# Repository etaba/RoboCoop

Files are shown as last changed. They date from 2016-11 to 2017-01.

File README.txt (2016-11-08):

To set the alarms:
	1) Basic operation: Click NEXT to cycle through the different RoboCoop settings. Click SEL to interact with a setting.
	2) To set the alarms: Cycle through the 4 alarm-setting screens and change the 	hours and minutes of the alarms by using SEL to increase the value.
	3) To set the time: Press NEXT until the screen says SETTING TIME. Press SEL to select the hour. Press NEXT and then repeat to select the minute.
	4) To toggle the alarm on and off, press SEL while on the first screen which displays the time and the state of the alarm.
	5) To disconnect the motor from the pulley, pull apart the pulley bolt from the magnetic bit socket of the motor. The motor pivots downward to make this possible. The pulley is then free and the door can be adjusted. Note that the solenoid door lock will need to be pushed in to allow the door to close
	6) If the screen reads "ERROR", it has fallen in a bad state and must be manually readjusted. Unplug RoboCoop and follow the instructions to manually readjust the door. When the door is closed and locked, restart RoboCoop.

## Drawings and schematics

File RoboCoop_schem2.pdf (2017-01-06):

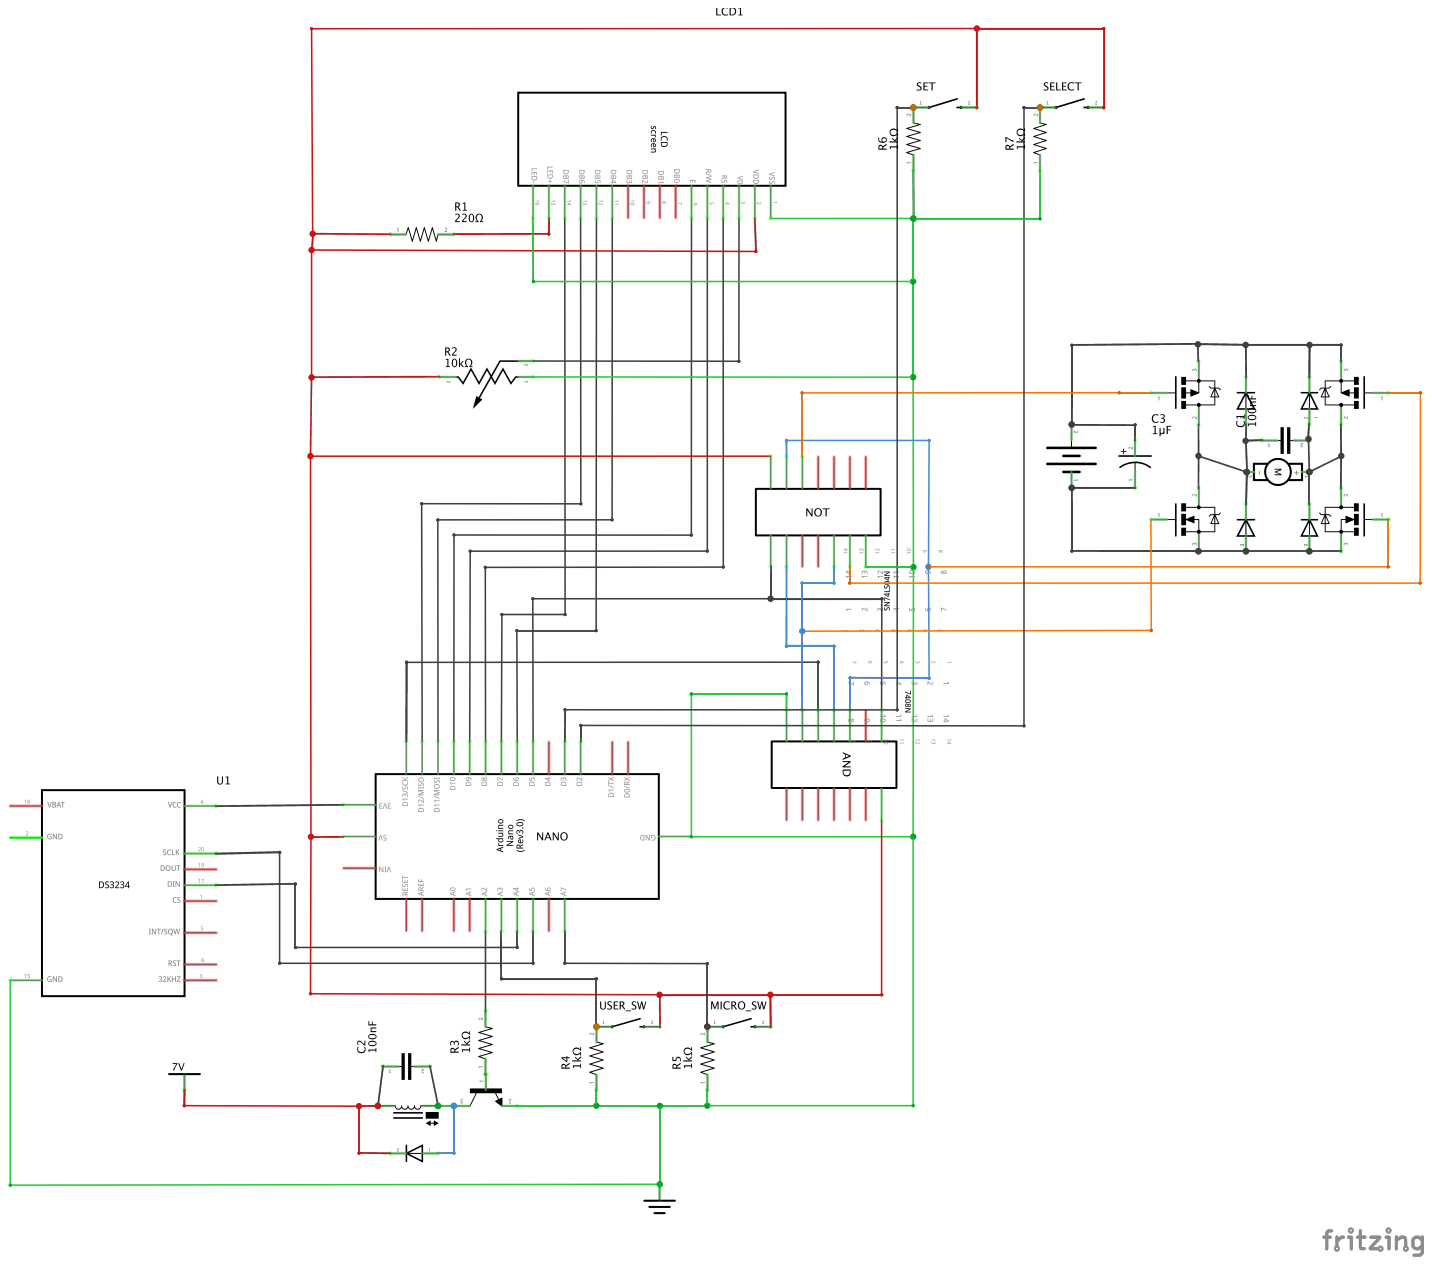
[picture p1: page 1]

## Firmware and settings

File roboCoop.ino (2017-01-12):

//v2.0

#include <Time.h>
#include <TimeLib.h>
#include "roboCoop.h"
#include <LiquidCrystal.h>
#include "Wire.h"
#define DS3231_I2C_ADDRESS 0x68


//inputs (switches)
int switch_p = A3; //D2
int doorStop_p = A7; //D3
int setButton_p = 2;
int selectButton_p = 3;

//outputs (to actuators)
int solenoidEn_p = A2;
int motorDirection_p = 5; //0 -> counter-clockwise, 1 -> clockwise
int motorEn_p = 4;

//LCD pins
int d4_p = 11;
int d5_p = 6;
int d6_p = 12;
int d7_p = 7;
int rs_p = 8;
int en_p = 10;
int rw_p = 9;

LiquidCrystal lcd(rs_p, en_p, d4_p, d5_p, d6_p, d7_p); 
String currScreen;

//state variables
int doorState; //0 -> closed, 1 -> open
int switchState; //0 -> switch off, 1 -> switch on
bool alarmState; //True -> alarm on
bool flipFlag; //To determine if the switch logic need to be reversed
int prevSwitchState; //To detect switch has been flipped
int currSwitchState;

TimeElements openAlarm;
TimeElements closeAlarm;
time_t timeOut;

machine_state_t machineState;
set_time_state_t setState;


void setup()
{
  Wire.begin();
  Serial.begin(9600);

  pinMode(13,OUTPUT);
  
  pinMode(motorDirection_p,OUTPUT);
  pinMode(motorEn_p, OUTPUT);
  pinMode(solenoidEn_p,OUTPUT);
  pinMode(rw_p,OUTPUT);
  
  pinMode(switch_p, INPUT);
  pinMode(setButton_p,INPUT);
  pinMode(selectButton_p,INPUT);
  pinMode(doorStop_p,INPUT);

  digitalWrite(motorEn_p, LOW);
  digitalWrite(motorDirection_p,LOW);
  digitalWrite(solenoidEn_p,LOW);
  digitalWrite(rw_p,LOW);
  
  //DEFAULT time and alarms   
  setCurrTime(12,0);
  openAlarm.Hour = 6;
  openAlarm.Minute = 30;
  closeAlarm.Hour = 20;
  closeAlarm.Minute = 0;

  alarmState = true;
  flipFlag = digitalRead(switch_p) == digitalRead2(doorStop_p);
  prevSwitchState = digitalRead(switch_p);
  machineState = READY;
}

void mockDoor(bool openDoor)
{
  if (openDoor)
  for(int i = 0; i < 5; i++)
  {
     digitalWrite(13,i%2);
     delay(500);
  }
  else
  for(int i = 0; i < 50; i++)
  {
     digitalWrite(13,i%2);
     delay(100);
  }
}

void loop()
{
  //for testing:
  if(false){
    while(digitalRead2(doorStop_p))
    {
      digitalWrite(13,HIGH);
      digitalWrite(solenoidEn_p,HIGH);
    }
    digitalWrite(13,LOW);
      digitalWrite(solenoidEn_p,LOW);
  }
  else{
  switch(machineState)
  {
    case READY:
      doorState = !digitalRead2(doorStop_p); //LOW->closed, HIGH->open
      currSwitchState = digitalRead(switch_p);
      switchState =  currSwitchState ^ flipFlag; //HIGH->on, LOW->off
      lcdShowTime("Time: ", getCurrTime(), (alarmState ? "Alarm On" : "Alarm Off"));
      if (currSwitchState != prevSwitchState &&
          switchState != doorState) //door must be opened or closed
      {
        machineState = (switchState==HIGH) ? OPENING : CLOSING;
      }
      prevSwitchState = currSwitchState;
      if(alarmState && doorState==LOW && checkAlarm(openAlarm))
      {
        machineState = OPENING;
        flipFlag = !flipFlag;
      }
      else if (alarmState && doorState==HIGH && checkAlarm(closeAlarm))
      {
        machineState = CLOSING;
        flipFlag = !flipFlag;
      }
      if (digitalRead(setButton_p) == HIGH)
      {
         machineState = SET;
         setState = OPEN_HOUR;
         timeOut = now();
         delay(500);
      }
      if (digitalRead(selectButton_p) == HIGH) //toggle alarm
      {
        alarmState = !alarmState;
      }
      break;

    case SET:
      if (now() - timeOut > 60)
      {
        machineState = READY;
      }
      switch(setState)
      {
        case OPEN_HOUR:
          lcdShowTime("Open at: ",openAlarm, "SETTING HOUR");
          if (digitalRead(selectButton_p)==HIGH)
          {
            if (openAlarm.Hour == 23)
              openAlarm.Hour = 0;
            else
              openAlarm.Hour += 1;
            delay(250);
          }
          if (digitalRead(setButton_p))
          {
            setState = OPEN_MINUTE;
            timeOut = now();
            delay(500);
          }
          break;
          
        case OPEN_MINUTE: 
          lcdShowTime("Open at: ",openAlarm,"SETTING MINUTE");
          if (digitalRead(selectButton_p)==HIGH)
          {
            if (openAlarm.Minute == 59)
              openAlarm.Minute = 0;
            else
              openAlarm.Minute += 1;
            delay(250);
          }
          if (digitalRead(setButton_p))
          {
            setState = CLOSE_HOUR;
            timeOut = now();
            delay(500); 
          }
          break;
          
        case CLOSE_HOUR:
          lcdShowTime("Close at: ",closeAlarm,"SETTING HOUR");
          if (digitalRead(selectButton_p)==HIGH)
          {
            if (closeAlarm.Hour == 23)
              closeAlarm.Hour = 0;
            else
              closeAlarm.Hour += 1;
            delay(250);
          }
          if (digitalRead(setButton_p))
          {
            setState = CLOSE_MINUTE;
            timeOut = now();
            delay(500); 
          }
          break;
          
        case CLOSE_MINUTE: 
          lcdShowTime("Close at: ",closeAlarm,"SETTING MINUTE");
          if (digitalRead(selectButton_p)==HIGH)
          {
            if (closeAlarm.Minute == 59)
              closeAlarm.Minute = 0;
            else
              closeAlarm.Minute += 1;
            delay(250);
          }
          if (digitalRead(setButton_p))
          {
            setState = TIME_HOUR;
            timeOut = now();
            delay(500); 
          }
          break;

        case TIME_HOUR:
          {
            TimeElements currTime = getCurrTime();
            lcdShowTime("Time: ",currTime,"SETTING HOUR");
            if (digitalRead(selectButton_p)==HIGH)
            {
              if (currTime.Hour == 23)
                currTime.Hour = 0;
              else
                currTime.Hour += 1;
              setCurrTime(currTime.Hour, currTime.Minute);
              delay(250);
            }
            if (digitalRead(setButton_p))
            {
              setState = TIME_MINUTE;
              timeOut = now();
              delay(500); 
            }
          }
          break;

        case TIME_MINUTE:
        {
          TimeElements t = getCurrTime();
          lcdShowTime("Time: ",t,"SETTING MINUTE");
          if (digitalRead(selectButton_p)==HIGH)
          {
            if (t.Minute == 59)
              t.Minute = 0;
            else
              t.Minute += 1;
            setCurrTime(t.Hour, t.Minute);
            delay(250);
          }
          if (digitalRead(setButton_p))
          {
            currSwitchState = digitalRead(switch_p);
            machineState = READY;
            delay(500); 
          }
        }
        break;
      }
      break;
    case OPENING: //activate door
      if (!operateDoor(HIGH))
      {
        machineState = ERROR_STATE;
      }
      else
      {
        machineState = READY;
      }
      break;
    case CLOSING:
      if (!operateDoor(LOW))
      {
        machineState = ERROR_STATE;
      }
      else
      {
        machineState = READY;
      }
      break;
    case MANUAL: //manual operation of door
      while(currSwitchState != digitalRead(switch_p))
      {
        digitalWrite(motorDirection_p,HIGH);
        digitalWrite(motorEn_p,HIGH);
        digitalWrite(solenoidEn_p,HIGH);
      }
      digitalWrite(solenoidEn_p,LOW);
      digitalWrite(motorEn_p,LOW);
      while(digitalRead(selectButton_p))
      {
        digitalWrite(motorDirection_p,LOW);
        digitalWrite(motorEn_p,HIGH);
        digitalWrite(solenoidEn_p,HIGH);
      }
      digitalWrite(solenoidEn_p,LOW);
      digitalWrite(motorEn_p,LOW);
      if (digitalRead(setButton_p))
      {
        flipFlag = digitalRead(switch_p) == digitalRead2(doorStop_p);
        machineState = READY;
        delay(500); 
      }
      break;
    case ERROR_STATE: //error, to prompt user to reset system
      lcdPrint("     ERROR!","RESET MANUALLY");
      delay (10000);
      break;
  }
  }
}

void lcdPrint(String header, String sub)
{
  lcd.clear();
  lcd.begin(16, 2);
  lcd.print(header);
  lcd.setCursor(1,2);
  lcd.print(sub);
}

void lcdShowTime(String prefix, TimeElements t, String details)
{
  
  String formattedTime = formatTime(t.Hour,t.Minute); 
  // Print a message to the LCD.
  if (currScreen != formattedTime + details)
  {
    lcd.clear();
    lcd.begin(16, 2);
    lcd.print(prefix + formattedTime);
    currScreen = formattedTime + details;
    if (details != "")
    {
      lcd.setCursor(1,2);
      lcd.print(details);
    }
  }
}

String formatTime(int t_hour, int t_minute)
{
  String dispHour;
  String dispMinute;
  dispHour = t_hour < 10 ? "0" + String(t_hour) : String(t_hour);
  dispMinute = t_minute < 10 ? "0" + String(t_minute) : String(t_minute);
  return dispHour + ":" + dispMinute;
}

bool operateDoor(bool openDoor) 
{
  //mockDoor(openDoor);
  //return;
  //digitalWrite(13,HIGH);
  time_t start = now();
  digitalWrite(motorDirection_p, !openDoor);
  if (openDoor && digitalRead2(doorStop_p)) //opening door
  {
    digitalWrite(solenoidEn_p, HIGH);
    delay(250); //TODO: calibrate
    digitalWrite(motorEn_p,HIGH);
    delay(1000);
    if (digitalRead2(doorStop_p)) //error if microswitch still closed after opening door for 500ms
    {
      digitalWrite(motorEn_p, LOW);
      digitalWrite(solenoidEn_p,LOW);
      return false;
    }
    delay (1750 );
    digitalWrite(motorEn_p,LOW);
    digitalWrite(solenoidEn_p, LOW);
  }
  else //closing door
  {
    digitalWrite(motorEn_p, HIGH);
    digitalWrite(solenoidEn_p,HIGH);
    while (!digitalRead2(doorStop_p))
    {
        if (now() - start > 3) //something is blocking the door or messing with the microswitch
        {
          digitalWrite(motorEn_p, LOW);
          digitalWrite(solenoidEn_p,LOW);
          return false;
        }
        delay(1);
    }
    digitalWrite(motorEn_p, LOW);
    digitalWrite(solenoidEn_p,LOW);
  }
  digitalWrite(13,LOW);
  delay(1000);
  return true;
}

bool checkAlarm(TimeElements alarm)
{
  byte t_second, t_minute, t_hour, dayOfWeek, dayOfMonth, t_month, t_year;
  readDS3231time(&t_second, &t_minute, &t_hour, &dayOfWeek, &dayOfMonth, &t_month, &t_year);
  return (alarm.Hour == int(t_hour) && alarm.Minute == int(t_minute) && int(t_second) == 0) ? true : false; 
}

// Convert normal decimal numbers to binary coded decimal
byte decToBcd(byte val)
{
  return( (val/10*16) + (val%10) );
}
// Convert binary coded decimal to normal decimal numbers
byte bcdToDec(byte val)
{
  return( (val/16*10) + (val%16) );
}

void setDS3231time(byte t_second, byte t_minute, byte t_hour, byte dayOfWeek, byte
dayOfMonth, byte t_month, byte t_year)
{
  // sets time and date data to DS3231
  Wire.beginTransmission(DS3231_I2C_ADDRESS);
  Wire.write(0); // set next input to start at the seconds register
  Wire.write(decToBcd(t_second)); // set seconds
  Wire.write(decToBcd(t_minute)); // set minutes
  Wire.write(decToBcd(t_hour)); // set hours
  Wire.write(decToBcd(dayOfWeek)); // set day of week (1=Sunday, 7=Saturday)
  Wire.write(decToBcd(dayOfMonth)); // set date (1 to 31)
  Wire.write(decToBcd(t_month)); // set t_month
  Wire.write(decToBcd(t_year)); // set t_year (0 to 99)
  Wire.endTransmission();
}
void readDS3231time(byte *t_second,
byte *t_minute,
byte *t_hour,
byte *dayOfWeek,
byte *dayOfMonth,
byte *t_month,
byte *t_year)
{
  Wire.beginTransmission(DS3231_I2C_ADDRESS);
  Wire.write(0); // set DS3231 register pointer to 00h
  Wire.endTransmission();
  Wire.requestFrom(DS3231_I2C_ADDRESS, 7);
  // request seven bytes of data from DS3231 starting from register 00h
  *t_second = bcdToDec(Wire.read() & 0x7f);
  *t_minute = bcdToDec(Wire.read());
  *t_hour = bcdToDec(Wire.read() & 0x3f);
  *dayOfWeek = bcdToDec(Wire.read());
  *dayOfMonth = bcdToDec(Wire.read());
  *t_month = bcdToDec(Wire.read());
  *t_year = bcdToDec(Wire.read());

}
void setCurrTime(int h, int m)
{
  byte t_second, t_minute, t_hour, dayOfWeek, dayOfMonth, t_month, t_year;
  t_second = 0;
  t_minute = m;
  t_hour = h;
  dayOfWeek = 1;
  dayOfMonth = 1;
  t_month = 1;
  t_year = 46;
  setDS3231time(t_second, t_minute, t_hour, dayOfWeek, dayOfMonth, t_month, t_year);
}
TimeElements getCurrTime()
{
  byte t_second, t_minute, t_hour, dayOfWeek, dayOfMonth, t_month, t_year;
  readDS3231time(&t_second, &t_minute, &t_hour, &dayOfWeek, &dayOfMonth, &t_month, &t_year);
  
  TimeElements currTime;
  currTime.Hour = (int)t_hour;
  currTime.Minute = (int)t_minute;
  return currTime;
}

//Below is ugliest hack ive written. 
//I'm ashamed of it and it keeps me up at night, but i was too lazy to rewire
//the reed switch to a digital pin. 
//My deepest apologies to anyone that has the misfortune of seeing this
bool digitalRead2(int pin)
{
  int analogV = analogRead(pin);
  return analogV > 900 ? true : false;
}
/*
void displayTime()
{
  byte t_second, t_minute, t_hour, dayOfWeek, dayOfMonth, t_month, t_year;
  // retrieve data from DS3231
  readDS3231time(&t_second, &t_minute, &t_hour, &dayOfWeek, &dayOfMonth, &t_month,
  &t_year);
  // send it to the serial monitor
  Serial.print(t_hour, DEC);
  // convert the byte variable to a decimal number when displayed
  Serial.print(":");
  if (t_minute<10)
  {
    Serial.print("0");
  }
  Serial.print(t_minute, DEC);
  Serial.print(":");
  if (t_second<10)
  {
    Serial.print("0");
  }
  Serial.print(t_second, DEC);
  Serial.print(" ");
  Serial.print(dayOfMonth, DEC);
  Serial.print("/");
  Serial.print(t_month, DEC);
  Serial.print("/");
  Serial.print(t_year, DEC);
  Serial.print(" Day of week: ");
  switch(dayOfWeek){
  case 1:
    Serial.println("Sunday");
    break;
  case 2:
    Serial.println("Monday");
    break;
  case 3:
    Serial.println("Tuesday");
    break;
  case 4:
    Serial.println("Wednesday");
    break;
  case 5:
    Serial.println("Thursday");
    break;
  case 6:
    Serial.println("Friday");
    break;
  case 7:
    Serial.println("Saturday");
    break;
  }
}
*/

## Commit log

2016-01-08 committing fritzing proj
    [RoboCoop.fzz]
2016-01-27 motor test
    [RoboCoop.fzz]
2016-03-02 decoupled switch logic from actual starting switch position
    [Enclosure.skp]
2016-03-24 fixed timer
    [Enclosure.skp]
2016-06-07 loft update
    [Loft_4.skp]
2016-11-01 cleaned out loft stuff
    [Enclosure.skp, Loft_4.skp]
2016-11-08 fix for case where something blocks door from closing
    [roboCoop.ino]
2016-11-08 replaced exception handling with function feedback
    [roboCoop.ino]
2016-11-09 added error catching for door open routine
    [roboCoop.ino]
2017-01-06 integrated external RTC
    [RoboCoop.fzz]
